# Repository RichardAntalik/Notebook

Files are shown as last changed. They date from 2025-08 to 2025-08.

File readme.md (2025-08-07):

# RPI CM5 based notebook

The design of small notebook with 8 inch display.
This is mainly a fun project, excersise in device production capability and integration
of complex systems at my home lab.

At revision 3 most subsystems are tested and working, but not as a whole.

## Features
- Smol
- 2 layer PCB layout! Optimized for home production
- Has integrated power management for 1S lipo pack
- Implements 4xUSB + 2 internal ports, 1x HDMI + 1 internal HDMI and DSI/CSI, PCIe, GPIO in card format and simple sound output

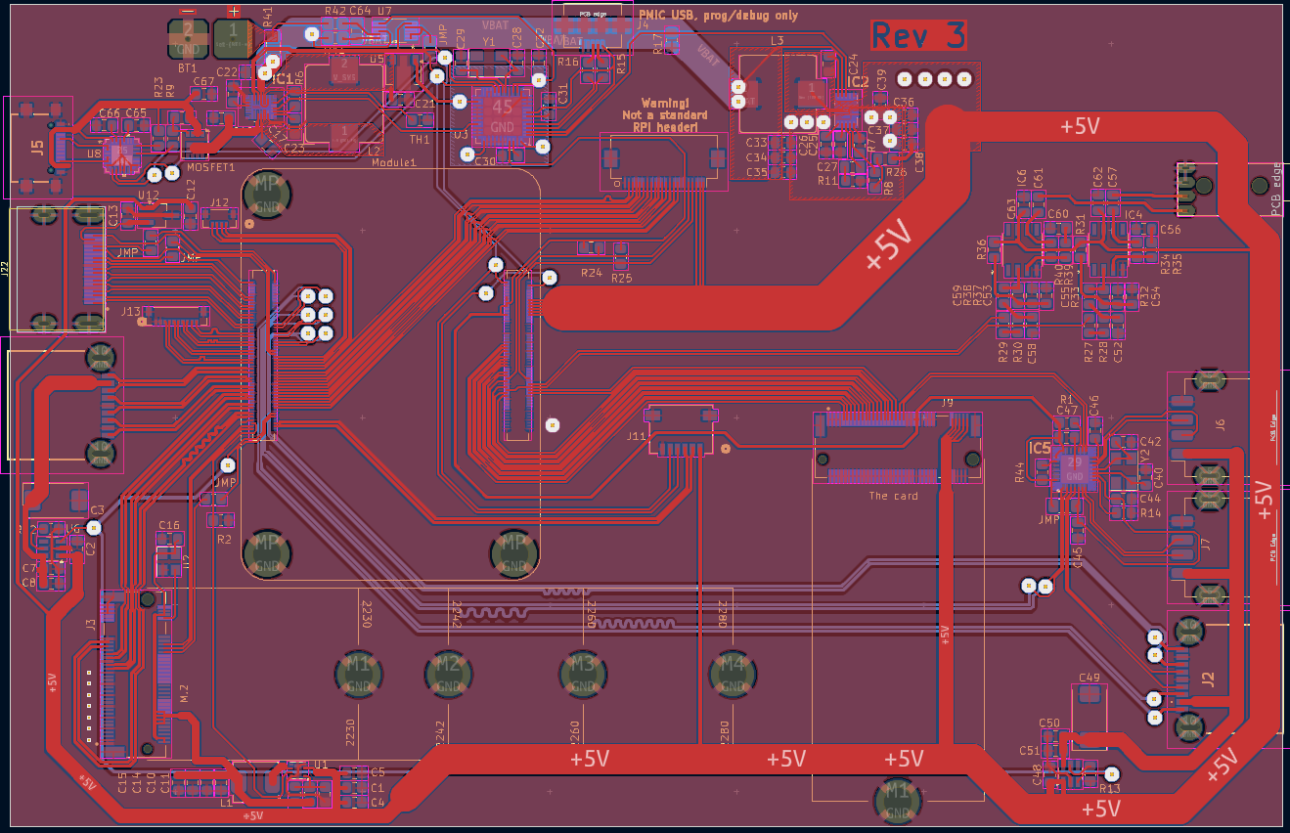
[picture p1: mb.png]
Main board


## TODO
- Custom keyboard with some touchpad or trackball or whatnot
- Display board
- Case

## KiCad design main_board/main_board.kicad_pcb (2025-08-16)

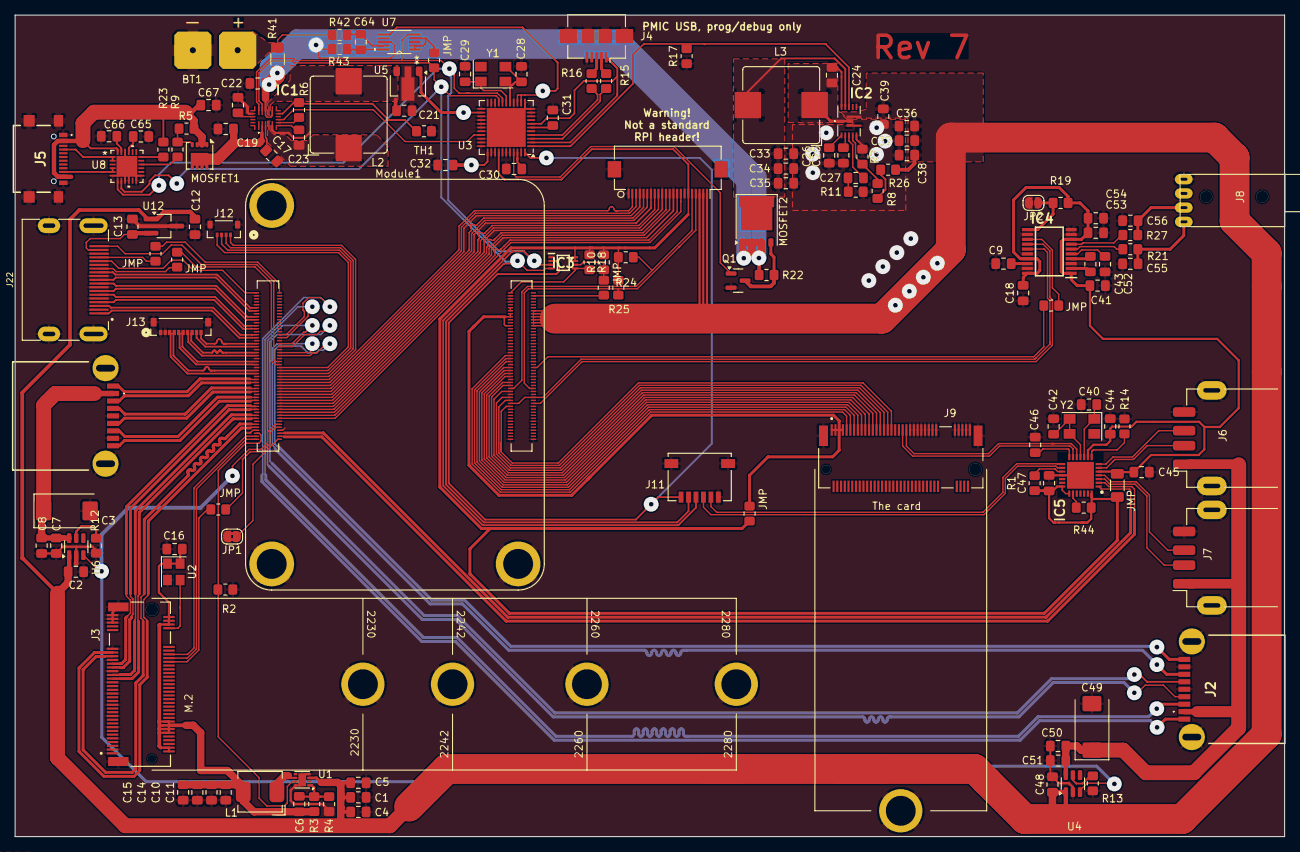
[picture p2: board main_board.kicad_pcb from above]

Board: 2 copper layers, 170.0 x 110.0 mm, 139 parts (0 on the bottom side), 161 nets.

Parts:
BT1: Battery_Cell; Bat_terminal
C1, C2, C4, C7, C8, C10, C11, C14, C15, C17, C20, C21, C22, C26, C48, C50, C51, C54: 10u; C_0805_2012Metric_Pad1.18x1.45mm_HandSolder
C3, C49: 100uF; CP_EIA-7343-31_Kemet-D
C5, C9, C12, C13, C16, C18, C24, C25, C39, C41, C44, C45, C46, C47, C53, C64: 100n; C_0805_2012Metric_Pad1.18x1.45mm_HandSolder
C6: 10nF; C_0805_2012Metric_Pad1.18x1.45mm_HandSolder
C19, C30, C31, C32, C65, C66, C67: 1u; C_0805_2012Metric_Pad1.18x1.45mm_HandSolder
C23, C27: 10n; C_0805_2012Metric_Pad1.18x1.45mm_HandSolder
C28, C29, C40, C42: 22p; C_0805_2012Metric_Pad1.18x1.45mm_HandSolder
C33, C34, C35, C36, C37, C38: 22u; C_0805_2012Metric_Pad1.18x1.45mm_HandSolder
C43, C52: 2u2; C_0805_2012Metric_Pad1.18x1.45mm_HandSolder
C55, C56: 2n2; C_0805_2012Metric_Pad1.18x1.45mm_HandSolder
IC1: MP2722GRH-0000-Z; MP2722GRH0000Z
IC2: MP3429GL-Z; MP3431GLP
IC3: PCA9306DCUR; SOP50P310X90-8N
IC4: PCM5102APWR; SOP65P640X120-20N
IC5: CY7C65632-28LTXC; QFN50P500X500X80-29N-D
J1, J2: USB3_A; U3BU1ASMT1
J3: Bus_M.2_Socket_M; M.2 M Key socket
J4: USB_B_Micro; USB_Micro-B_Amphenol_10104110_Horizontal
J5: USB_C_Receptacle_USB2.0; USB421603A
J6, J7: USB_A; USB_A_Receptacle_GCT_USB1046
J8: AudioJack3; LUMBERG 1503 16
J9: The_card; Random card conn
J10: Conn_01x22_Female; Hirose_FH12-22S-0.5SH_1x22-1MP_P0.50mm_Horizontal
J11: 501568-0607-TR325; CONN_501568-0607-TR325_MOL
J12: SM04B-XSRS-ETBLFSN; CONN_SM04B-XSRS-ETB_JST
J13: SM10B-XSRS-ETB; CONN_SM10B-XSRS-ETB_JST
J22: 690-019-298-412; EDAC 690-019-298-412
JMP: R_0805_2012Metric_Pad1.20x1.40mm_HandSolder
JMP#2, JMP#3, JMP#5, JMP#6, JMP#7, JMP#8: R_0805_2012Metric_Pad1.20x1.40mm_HandSolder
JMP#4: 0.01R; R_1206_3216Metric_Pad1.30x1.75mm_HandSolder
JP1: Jumper_2_Bridged; SolderJumper-2_P1.3mm_Bridged2Bar_RoundedPad1.0x1.5mm
JP2: Jumper_2; SolderJumper-2_P1.3mm_Open_RoundedPad1.0x1.5mm
L1: 2.2uH; L_Bourns_SRP5030CC
L2: 4.7u; L_Bourns_SRP1038C_10.0x10.0mm
L3: 1.5u; L_Bourns_SRP1038C_10.0x10.0mm
MOSFET1: STL9P3LLH6; Diodes_PowerDI3333-8
MOSFET2: WMB60P02TS-CYG; PQFN-8-EP_6x5mm_P1.27mm_Generic
Module1: ComputeModule5-CM5; Raspberry-Pi-5-Compute-Module
Q1: Random N ch FET; SOT-23
R1, R9: 10K; R_0805_2012Metric_Pad1.20x1.40mm_HandSolder
R2: 100K 1%; R_0805_2012Metric_Pad1.20x1.40mm_HandSolder
R3, R17: 15K; R_0805_2012Metric_Pad1.20x1.40mm_HandSolder
R4: 3.3K; R_0805_2012Metric_Pad1.20x1.40mm_HandSolder
R5, R7, R19, R22: 100K; R_0805_2012Metric_Pad1.20x1.40mm_HandSolder
R6: R=NTC; R_0805_2012Metric_Pad1.20x1.40mm_HandSolder
R8: 68K; R_0805_2012Metric_Pad1.20x1.40mm_HandSolder
R10, R18, R24, R25: 2K; R_0805_2012Metric_Pad1.20x1.40mm_HandSolder
R11: 6.8K; R_0805_2012Metric_Pad1.20x1.40mm_HandSolder
R12, R13: 15K 1%; R_0805_2012Metric_Pad1.20x1.40mm_HandSolder
R14: 650R; R_0805_2012Metric_Pad1.20x1.40mm_HandSolder
R15, R16: 20R; R_0805_2012Metric_Pad1.20x1.40mm_HandSolder
R21, R27: 470R; R_0805_2012Metric_Pad1.20x1.40mm_HandSolder
R23: 1K; R_0805_2012Metric_Pad1.20x1.40mm_HandSolder
R26: 330K; R_0805_2012Metric_Pad1.20x1.40mm_HandSolder
R41: 0.01R; R_1206_3216Metric_Pad1.30x1.75mm_HandSolder
R42, R43: 10R; R_0805_2012Metric_Pad1.20x1.40mm_HandSolder
R44: 100k; R_0805_2012Metric_Pad1.20x1.40mm_HandSolder
TH1: β = 3435; R_0805_2012Metric_Pad1.20x1.40mm_HandSolder
U1: AP3441SHE-7B; DFN-8-1EP_2x2mm_P0.5mm_EP1.05x1.75mm
U2: ASEK-32.768KHZ-L-R-T; Crystal_SMD_3225-4Pin_3.2x2.5mm
U3: ATmega32U4-M; QFN-44-1EP_7x7mm_P0.5mm_EP5.2x5.2mm
U4, U6: AP22653W6; SOT-23-6
U5: AP2204RB-3.3; SOT-89-3
U7: INA220AIDGST; DGS10
U8: STUSB4500QTR; STUSB4500
U12: RT9742SNGV; TSOT-23_HandSoldering
Y1: Crystal; Crystal_SMD_5032-4Pin_5.0x3.2mm
Y2: 12MHz; Crystal_SMD_5032-4Pin_5.0x3.2mm

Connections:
/Battery management/+5V: C1.1, C2.1, C4.1, C5.1, C12.1, C36.1, C37.1, C38.1, C39.1, C48.1, IC2.8 (VOUT), J10.20, J10.21, J10.22, Module1.77 (+5v_(Input)), Module1.79 (+5v_(Input)), Module1.81 (+5v_(Input)), Module1.83 (+5v_(Input)), Module1.85 (+5v_(Input)), Module1.87 (+5v_(Input)), R26.2, U1.3 (VIN), U4.1 (IN), U6.1 (IN), U12.1 (IN)
/Battery management/BOOST_EN: IC2.11 (EN), R17.2, U3.1 (PE6)
/Battery management/PMIC_3.3V: C32.2, IC3.2 (VREF1), J11.6, U3.13 (~RESET), U3.14 (VCC), U3.24 (AVCC), U3.34 (VCC), U3.44 (AVCC), U5.1 (VOUT), U7.6 (VS)
/Battery management/PMIC_IIC2_SCL: IC3.6 (SCL2), JMP#7.1, JMP#7.2, Module1.97 (CAM_GPIO0), R10.1
/Battery management/PMIC_IIC2_SDA: IC3.5 (SDA2), Module1.100 (CAM_GPIO1), R18.2
/Battery management/PMIC_IIC_SCL: IC1.16 (SCL), IC3.3 (SCL1), J11.4, U3.18 (PD0), U7.5 (SCL), U8.7 (SCL)
/Battery management/PMIC_IIC_SDA: IC1.15 (SDA), IC3.4 (SDA1), J11.5, JMP#3.1, U3.19 (PD1), U7.1 (A1), U7.2 (A0), U7.4 (SDA), U8.8 (SDA)
/Battery management/VBAT: C22.1, IC1.12 (BATTSNS), IC1.14 (BATT), MOSFET2.1 (S), MOSFET2.2 (S), MOSFET2.3 (S), R22.2, R41.2, R43.2, U7.8 (VBUS)
/Battery management/V_SYS: C21.1, IC1.13 (SYS), L2.2, U5.3 (VIN)
/CM5_GPIO/+1.8v: Module1.88 (+1.8v_(Output)), Module1.90 (+1.8v_(Output))
/CM5_GPIO/+3.3v: C18.1, C41.2, C44.1, C45.1, C47.1, C53.2, C54.2, IC3.7 (VREF2), IC3.8 (EN), IC4.1 (CPVDD), IC4.8 (AVDD), IC4.17 (XSMT), IC4.20 (DVDD), IC5.5 (VCC_A_1), IC5.9 (VCC_A_2), IC5.21 (VCC_D), IC5.22 (SELFPWR), IC5.28 (VREG), J9.1, J9.3, J9.5, J9.7, J10.17, JMP#4.1, JMP#4.2, JMP#5.1, JMP#5.2, Module1.78 (GPIO_VREF(1.8v/3.3v_Input)), Module1.84 (+3.3v_(Output)), Module1.86 (+3.3v_(Output)), R1.1, R10.2, R18.1, R19.2, R24.1, R25.1, R44.1, U3.37 (PF6)
/CM5_GPIO/DPHY1_SCL: J10.19, Module1.35 (ID_SC), R25.2
/CM5_GPIO/DPHY1_SDA: J10.18, Module1.36 (ID_SD), R24.2
/CM5_GPIO/GP2: J9.9, Module1.58 (GPIO2)
/CM5_GPIO/GP3: J9.11, Module1.56 (GPIO3)
/CM5_GPIO/GP4: J9.13, Module1.54 (GPIO4)
/CM5_GPIO/GP5: J9.27, Module1.34 (GPIO5)
/CM5_GPIO/GP6: J9.29, Module1.30 (GPIO6)
/CM5_GPIO/GP9: J9.23, Module1.40 (GPIO9)
/CM5_GPIO/GP10: J9.21, Module1.44 (GPIO10)
/CM5_GPIO/GP11: J9.25, Module1.38 (GPIO11)
/CM5_GPIO/GP13: J9.31, Module1.28 (GPIO13)
/CM5_GPIO/GP17: J9.15, Module1.50 (GPIO17)
/CM5_GPIO/GP22: J9.19, Module1.46 (GPIO22)
/CM5_GPIO/GP26: J9.33, Module1.24 (GPIO26)
/CM5_GPIO/GP27: J9.17, Module1.48 (GPIO27)
/CM5_GPIO/GPIO16: IC4.15 (LRCK), Module1.26 (GPIO19), Module1.29 (GPIO16)
/CM5_GPIO/I2SCLK: IC4.13 (BCK), JMP#6.1, JMP#6.2, Module1.49 (GPIO18)
/CM5_HighSpeed/DPHY0_C_N: J10.9, Module1.127 (MIPI0_C_N)
/CM5_HighSpeed/DPHY0_C_P: J10.8, Module1.129 (MIPI0_C_P)
/CM5_HighSpeed/DPHY0_D0_N: J10.15, Module1.115 (MIPI0_D0_N)
/CM5_HighSpeed/DPHY0_D0_P: J10.14, Module1.117 (MIPI0_D0_P)
/CM5_HighSpeed/DPHY0_D1_N: J10.12, Module1.121 (MIPI0_D1_N)
/CM5_HighSpeed/DPHY0_D1_P: J10.11, Module1.123 (MIPI0_D1_P)
/CM5_HighSpeed/DPHY0_D2_N: J10.6, Module1.133 (MIPI0_D2_N)
/CM5_HighSpeed/DPHY0_D2_P: J10.5, Module1.135 (MIPI0_D2_P)
/CM5_HighSpeed/DPHY0_D3_N: J10.3, Module1.139 (MIPI0_D3_N)
/CM5_HighSpeed/DPHY0_D3_P: J10.2, Module1.141 (MIPI0_D3_P)
/CM5_HighSpeed/HDMI0_CEC: J22.13 (CEC), JMP#2.1, JMP#2.2, Module1.151 (HDMI0_CEC)
/CM5_HighSpeed/HDMI0_CK_N: J22.12 (CK-), Module1.190 (HDMI0_CLK_N)
/CM5_HighSpeed/HDMI0_CK_P: J22.10 (CK+), Module1.188 (HDMI0_CLK_P)
/CM5_HighSpeed/HDMI0_D0_N: J22.9 (D0-), Module1.184 (HDMI0_TX0_N)
/CM5_HighSpeed/HDMI0_D0_P: J22.7 (D0+), Module1.182 (HDMI0_TX0_P)
/CM5_HighSpeed/HDMI0_D1_N: J22.6 (D1-), Module1.178 (HDMI0_TX1_N)
/CM5_HighSpeed/HDMI0_D1_P: J22.4 (D1+), Module1.176 (HDMI0_TX1_P)
/CM5_HighSpeed/HDMI0_D2_N: J22.3 (D2-), Module1.172 (HDMI0_TX2_N)
/CM5_HighSpeed/HDMI0_D2_P: J22.1 (D2+), Module1.170 (HDMI0_TX2_P)
/CM5_HighSpeed/HDMI0_HOTPLUG: J22.19 (HPD/HEAC-), Module1.153 (HDMI0_HOTPLUG)
/CM5_HighSpeed/HDMI0_SCL: J22.15 (SCL), Module1.200 (HDMI0_SCL)
/CM5_HighSpeed/HDMI0_SDA: J22.16 (SDA), JMP#8.1, JMP#8.2, Module1.199 (HDMI0_SDA)
/CM5_HighSpeed/HDMI1_CEC: J12.4, Module1.149 (HDMI1_CEC)
/CM5_HighSpeed/HDMI1_CK_N: J13.10, Module1.166 (HDMI1_CLK_N)
/CM5_HighSpeed/HDMI1_CK_P: J13.9, Module1.164 (HDMI1_CLK_P)
/CM5_HighSpeed/HDMI1_D0_N: J13.8, Module1.160 (HDMI1_TX0_N)
/CM5_HighSpeed/HDMI1_D0_P: J13.7, Module1.158 (HDMI1_TX0_P)
/CM5_HighSpeed/HDMI1_D1_N: J13.6, Module1.154 (HDMI1_TX1_N)
/CM5_HighSpeed/HDMI1_D1_P: J13.5, Module1.152 (HDMI1_TX1_P)
/CM5_HighSpeed/HDMI1_D2_N: J13.4, Module1.148 (HDMI1_TX2_N)
/CM5_HighSpeed/HDMI1_D2_P: J13.3, Module1.146 (HDMI1_TX2_P)
/CM5_HighSpeed/HDMI1_HOTPLUG: J12.1, Module1.143 (HDMI1_HOTPLUG)
/CM5_HighSpeed/HDMI1_SCL: J12.3, Module1.147 (HDMI1_SCL)
/CM5_HighSpeed/HDMI1_SDA: J12.2, Module1.145 (HDMI1_SDA)
/CM5_HighSpeed/HDMI_5v: C13.1, J22.18 (+5V), U12.2 (OUT)
/CM5_HighSpeed/PCIE_CLK_N: J3.53 (REFCLKn), Module1.112 (PCIe_CLK_N)
/CM5_HighSpeed/PCIE_CLK_P: J3.55 (REFCLKp), Module1.110 (PCIe_CLK_P)
/CM5_HighSpeed/PCIE_PWR_EN: Module1.106 (PCIE_PWR_EN), R2.1, U1.7 (EN)
/CM5_HighSpeed/PCIE_RX_N: J3.43 (PETp0), Module1.118 (PCIe_RX_N)
/CM5_HighSpeed/PCIE_RX_P: J3.41 (PETn0), Module1.116 (PCIe_RX_P)
/CM5_HighSpeed/PCIE_TX_N: J3.49 (PERp0), Module1.124 (PCIe_TX_N)
/CM5_HighSpeed/PCIE_TX_P: J3.47 (PERn0), Module1.122 (PCIe_TX_P)
/CM5_HighSpeed/PCIE_nCLKREQ: J3.52 (~CLKREQ), Module1.102 (PCIe_nCLKREQ)
/CM5_HighSpeed/PCIE_nRST: J3.50 (~PERST), JMP.1, JMP.2, Module1.109 (PCIe_nRST)
/CM5_HighSpeed/PCIE_nWAKE: J3.54 (~PEWAKE), Module1.104 (PCIE_nWAKE)
/CM5_HighSpeed/USB2_N: IC5.1 (D-), Module1.105 (USB2_P)
/CM5_HighSpeed/USB2_P: IC5.2 (D+), Module1.103 (USB2_N)
/CM5_HighSpeed/USB3-0-D_N: J1.2 (D-), Module1.136 (USB3-0-D_N)
/CM5_HighSpeed/USB3-0-D_P: J1.3 (D+), Module1.134 (USB3-0-D_P)
/CM5_HighSpeed/USB3-0-RX_N: J1.5 (SSRX-), Module1.128 (USB3-0-RX_N)
/CM5_HighSpeed/USB3-0-RX_P: J1.6 (SSRX+), Module1.130 (USB3-0-RX_P)
/CM5_HighSpeed/USB3-0-TX_N: J1.8 (SSTX-), Module1.140 (USB3-0-TX_N)
/CM5_HighSpeed/USB3-0-TX_P: J1.9 (SSTX+), Module1.142 (USB3-0-TX_P)
/CM5_HighSpeed/VBUS: C3.1, C7.1, C8.1, J1.1 (VBUS), U6.6 (OUT)
/CM5_HighSpeed/VBUS_EN: Module1.111 (VBUS_EN), U4.3 (EN), U6.3 (EN)
/PCIe-M2/FB: C6.2, R3.2, R4.1, U1.1 (FB)
/PCIe-M2/M2_3v3: C6.1, C10.1, C11.1, C14.1, C15.1, C16.1, J3.2 (3.3V), J3.4 (3.3V), J3.12 (3.3V), J3.14 (3.3V), J3.16 (3.3V), J3.18 (3.3V), J3.70 (3.3V), J3.72 (3.3V), J3.74 (3.3V), L1.2, R3.1, U2.1 (EN), U2.4 (VDD)
/The card/USB2_2_DN: IC5.12 (DD-[3]), J9.41
/The card/USB2_2_DP: IC5.13 (DD+[3]), J9.39
/USB hub/VBUS2: C49.1, C50.1, C51.1, J2.1 (VBUS), J6.1 (VBUS), J7.1 (VBUS), U4.6 (OUT)
GND: BT1.2 (-), C1.2, C2.2, C3.2, C4.2, C5.2, C7.2, C8.2, C9.2, C10.2, C11.2, C12.2, C13.2, C14.2, C15.2, C16.2, C17.2, C18.2, C19.2, C20.2, C21.2, C22.2, C25.1, C26.1, C28.2, C29.2, C30.1, C31.1, C32.1, C33.2, C34.2, C35.2, C36.2, C37.2, C38.2, C39.2, C40.2, C41.1, C42.2, C44.2, C45.2, C46.2, C47.2, C48.2, C49.2, C50.2, C51.2, C52.1, C53.1, C54.1, C55.1, C56.1, C65.2, C66.2, C67.2, IC1.5 (PGND), IC1.18 (AGND), IC2.6 (AGND), IC2.7 (PGND), IC2.9 (FTY), IC3.1 (GND), IC4.3 (CPGND), IC4.9 (AGND), IC4.10 (DEMP), IC4.12 (SCK), IC4.16 (FMT), IC4.19 (DGND), IC5.18 (TEST/_I2C_SCL), IC5.29 (EP), J1.4 (GND), J1.7 (DRAIN), J1.10 (SHIELD), J2.4 (GND), J2.7 (DRAIN), J2.10 (SHIELD), J3.1 (GND), J3.3 (GND), J3.9 (GND), J3.15 (GND), J3.21 (GND), J3.27 (GND), J3.33 (GND), J3.39 (GND), J3.45 (GND), J3.51 (GND), J3.57 (GND), J3.71 (GND), J3.73 (GND), J3.75 (GND), J3.M1 (GND2230), J3.M2 (GND2242), J3.M3 (GND2260), J3.M4 (GND2280), J3.S1, J3.S2, J4.5 (GND), J4.6 (Shield), J5.A1 (GND), J5.B1 (GND), J5.S1 (SHIELD), J6.4 (GND), J6.5 (Shield), J7.4 (GND), J7.5 (Shield), J8.S, J9.43, J9.45, J9.47, J9.49, J9.51, J9.53, J9.55, J9.57, J9.67, J9.69, J9.71, J9.73, J9.75, J9.M1 (GND2230), J9.S1, J9.S2, J10.1, J10.4, J10.7, J10.10, J10.13, J10.16, J10.MP, J11.1, J11.7, J11.8, J12.5, J12.6, J13.1, J13.2, J13.11, J13.12, J22.2 (D2S), J22.5 (D1S), J22.8 (D0S), J22.11 (CKS), J22.17 (GND), J22.SH1 (SH), J22.SH2 (SH), J22.SH3 (SH), J22.SH4 (SH), JP1.2 (B), JP2.2 (B), Module1.1 (GND), Module1.2 (GND), Module1.7 (GND), Module1.8 (GND), Module1.13 (GND), Module1.14 (GND), Module1.22 (GND), Module1.23 (GND), Module1.32 (GND), Module1.33 (GND), Module1.42 (GND), Module1.43 (GND), Module1.52 (GND), Module1.53 (GND), Module1.59 (GND), Module1.60 (GND), Module1.65 (GND), Module1.66 (GND), Module1.71 (GND), Module1.74 (GND), Module1.94 (CC1), Module1.96 (CC2), Module1.98 (GND), Module1.107 (GND), Module1.108 (GND), Module1.113 (GND), Module1.114 (GND), Module1.119 (GND), Module1.120 (GND), Module1.125 (GND), Module1.126 (GND), Module1.131 (GND), Module1.132 (GND), Module1.137 (GND), Module1.138 (GND), Module1.144 (GND), Module1.150 (GND), Module1.155 (GND), Module1.156 (GND), Module1.161 (GND), Module1.162 (GND), Module1.167 (GND), Module1.168 (GND), Module1.173 (GND), Module1.174 (GND), Module1.179 (GND), Module1.180 (GND), Module1.185 (GND), Module1.186 (GND), Module1.191 (GND), Module1.192 (GND), Module1.197 (GND), Module1.198 (GND), Module1.MP, Q1.2 (S), R2.2, R4.2, R7.1, R11.1, R12.1, R13.2, R14.2, R17.1, TH1.2, U1.4 (PGND), U1.8 (SGND), U1.9 (PAD), U2.2 (GND), U3.5 (UGND), U3.9 (PB1), U3.10 (PB2), U3.11 (PB3), U3.12 (PB7), U3.15 (GND), U3.20 (PD2), U3.21 (PD3), U3.23 (GND), U3.25 (PD4), U3.26 (PD6), U3.27 (PD7), U3.28 (PB4), U3.29 (PB5), U3.31 (PC6), U3.32 (PC7), U3.33 (~HWB/PE2), U3.35 (GND), U3.36 (PF7), U3.38 (PF5), U3.39 (PF4), U3.40 (PF1), U3.43 (GND), U3.45 (GND), U4.2 (GND), U5.2 (GND), U6.2 (GND), U7.7 (GND), U8.6 (RESET), U8.9 (DISCH), U8.10 (GND), U8.12 (ADDR0), U8.13 (ADDR1), U8.22 (VSYS), U8.25 (EP), U12.3 (GND)
unnamed: BT1.1 (+), R41.1, R42.2
unnamed: C27.1, R11.2
unnamed: C55.2, J8.T, R21.1
unnamed: C56.2, J8.R1, R27.1
unnamed: C23.2, IC1.6 (BST_1)
unnamed: C19.1, IC1.2 (IN), MOSFET1.5 (D)
unnamed: IC1.10 (NTC1), R6.1, TH1.1
unnamed: C17.1, IC1.3 (PMID)
unnamed: C23.1, IC1.4 (SW), L2.1
unnamed: C20.1, IC1.19 (VCC)
unnamed: IC1.7 (VRNTC), R6.2
unnamed: IC1.8 (~INT), U3.30 (PB6)
unnamed: C24.1, IC2.13 (BST)
unnamed: C27.2, IC2.4 (COMP)
unnamed: IC2.5 (FB), R7.2, R8.1
unnamed: C25.2, IC2.3 (SS)
unnamed: C24.2, IC2.1 (SW), L3.1
unnamed: C26.2, IC2.2 (VDD)
unnamed: C33.1, C34.1, C35.1, IC2.12 (VIN), L3.2, MOSFET2.5 (D)
unnamed: C43.1, IC4.4 (CAPM)
unnamed: C43.2, IC4.2 (CAPP)
unnamed: IC4.14 (DIN), Module1.25 (GPIO21)
unnamed: IC4.11 (FLT), JP2.1 (A), R19.1
unnamed: C9.1, IC4.18 (LDOO)
unnamed: IC4.6 (OUTL), R21.2
unnamed: IC4.7 (OUTR), R27.2
unnamed: C52.2, IC4.5 (VNEG)
unnamed: IC5.4 (DD+[1]), J7.3 (D+)
unnamed: IC5.7 (DD+[2]), J6.3 (D+)
unnamed: IC5.16 (DD+[4]), J11.3
unnamed: IC5.3 (DD-[1]), J7.2 (D-)
unnamed: IC5.6 (DD-[2]), J6.2 (D-)
unnamed: IC5.15 (DD-[4]), J11.2
unnamed: IC5.23 (GANG), R44.2
unnamed: IC5.17 (RESET#), R1.2
unnamed: IC5.8 (RREF), R14.1
unnamed: C46.1, IC5.14 (VCC_A_3)
unnamed: C40.1, IC5.10 (XIN), Y2.1
unnamed: C42.1, IC5.11 (XOUT), Y2.2
unnamed: J2.3 (D+), Module1.163 (USB3-1-D_P)
unnamed: J2.2 (D-), Module1.165 (USB3-1-D_N)
unnamed: J2.6 (SSRX+), Module1.157 (USB3-1-RX_N)
unnamed: J2.5 (SSRX-), Module1.159 (USB3-1-RX_P)
unnamed: J2.9 (SSTX+), Module1.171 (USB3-1-TX_P)
unnamed: J2.8 (SSTX-), Module1.169 (USB3-1-TX_N)
unnamed: J3.68 (SUSCLK), U2.3 (Out)
unnamed: J4.3 (D+), R16.2
unnamed: J4.2 (D-), R15.2
unnamed: J4.1 (VBUS), U3.2 (UVCC), U3.7 (VBUS)
unnamed: J5.A5 (CC1), U8.1 (CC1DB), U8.2 (CC1)
unnamed: J5.B5 (CC2), U8.4 (CC2), U8.5 (CC2DB)
unnamed: JP1.1 (A), Module1.101 (USB_OTG_ID)
unnamed: MOSFET1.4 (G), R5.2, R9.1
unnamed: MOSFET2.4 (G), Q1.3 (D), R22.1
unnamed: Q1.1 (G), U3.41 (PF0)
unnamed: R8.2, R26.1
unnamed: L1.1, U1.6 (LX)
unnamed: C30.2, U3.42 (AREF)
unnamed: R16.1, U3.4 (D+)
unnamed: R15.1, U3.3 (D-)
unnamed: C31.2, U3.6 (UCAP)
unnamed: C29.1, U3.17 (XTAL1), Y1.1
unnamed: C28.1, U3.16 (XTAL2), Y1.2
unnamed: R13.1, U4.5 (ILIM)
unnamed: R12.2, U6.5 (ILIM)
unnamed: C64.2, R43.1, U7.10 (VIN+)
unnamed: C64.1, R42.1, U7.9 (VIN-)
unnamed: R9.2, U8.16 (VBUS_EN_SNK)
unnamed: R23.2, U8.18 (VBUS_VS_DISCH)
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

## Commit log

2025-06-30 Add main board project
    [CM5_GPIO.kicad_sch, CM5_HighSpeed.kicad_sch, PCIe-M2.kicad_sch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]
2025-06-30 Implement part of power management.
    [CM5_GPIO.kicad_sch, PCIe-M2.kicad_sch, bat.kicad_sch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]
2025-07-01 More power management goodness
    [CM5_GPIO.kicad_sch, CM5_HighSpeed.kicad_sch, PCIe-M2.kicad_sch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]
2025-07-02 Finalize power management
    [CM5_GPIO.kicad_sch, CM5_HighSpeed.kicad_sch, bat.kicad_sch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]
2025-07-03 Start reouting USB hub
    [CM5_HighSpeed.kicad_sch, bat.kicad_sch, main_board.kicad_pcb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]
2025-07-06 Bunch more routing, mainly added MIPI interface, reworked power management a bit
    [CM5_GPIO.kicad_sch, CM5_HighSpeed.kicad_sch, bat.kicad_sch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]
2025-07-12 Bunch of fixes + audio out interface
    [CM5_GPIO.kicad_sch, bat.kicad_sch, main_board.kicad_pcb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]
2025-07-12 Implement power monitoring
    [CM5_GPIO.kicad_sch, CM5_HighSpeed.kicad_sch, bat.kicad_sch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]
2025-07-13 Add expansion slot
    [CM5_GPIO.kicad_sch, bat.kicad_sch, main_board.kicad_pcb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]
2025-07-27 Rev 1 draft
    [CM5_HighSpeed.kicad_sch, PCIe-M2.kicad_sch, bat.kicad_sch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]
2025-07-27 Cleanup silks
    [main_board.kicad_pcb]
2025-07-28 Final fixes
    [bat.kicad_sch, main_board.kicad_pcb]
2025-07-28 Also update schematic
    [bat.kicad_sch]
2025-07-29 Fix fried USB hub
    [bat.kicad_sch, main_board.kicad_pcb]
2025-07-30 Fix frying usb hub again
    [main_board.kicad_pcb]
2025-07-30 Remove passives from hub
    [main_board.kicad_pcb, main_board.kicad_sch]
2025-07-30 Cleanup, improve ground situation
    [main_board.kicad_pcb]
2025-07-30 More ground improvements
    [main_board.kicad_pcb]
2025-08-04 Fix 32u4 high power consumption, improve QFN soldering with thick ass solder masks.
    [bat.kicad_sch, main_board.kicad_pcb]
2025-08-05 Make sure, that audio jack can be hand soldered, finalize rev 1 design.
    [CM5_GPIO.kicad_sch, main_board.kicad_pcb, main_board.kicad_sch]
2025-08-05 Fix bad jack footprint
    [main_board.kicad_pcb]
2025-08-05 Make all holes only 0.8mm for spot drilling only
    [main_board.kicad_pcb]
2025-08-05 Add battery polarity labels to cu layer, since mistake would be expensive
    [main_board.kicad_pcb]
2025-08-05 Change the board size, rev2
    [main_board.kicad_pcb]
2025-08-07 Revert all holes defaulting to 0.8mm as plotter can do this
    [main_board.kicad_pcb]
2025-08-07 Add mounting points to symbols
    [CM5_GPIO.kicad_sch, CM5_HighSpeed.kicad_sch, main_board.kicad_pcb]
2025-08-07 Make more space for the card
    [main_board.kicad_pcb]
2025-08-07 Change mech holes to TH for better hand spot drilling
    [main_board.kicad_pcb]
2025-08-07 Silk cleanup
    [main_board.kicad_pcb]
2025-08-07 Update readme and whatnot
    [main_board.kicad_pcb]
2025-08-10 Rev 4
    Fix some mistakes found during assembly
    [main_board.kicad_pcb]
2025-08-10 Fix bad output voltage
    For some reason I got 5V with previous values on prototype. Weird...
    [CM5_GPIO.kicad_sch, CM5_HighSpeed.kicad_sch, PCIe-M2.kicad_sch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]
2025-08-12 Fix critical problems
    - Adding USB2 hub on USB3 port did not work correctly
    - PM I2C bus was not working when CM5 is shut down
    - Missing OTG ID pin
    [CM5_GPIO.kicad_sch, CM5_HighSpeed.kicad_sch, bat.kicad_sch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]
2025-08-13 Fix CM5 not waking up when enabling boost
    When battery is fully charged, CM5 does not turn on.
    [CM5_GPIO.kicad_sch, CM5_HighSpeed.kicad_sch, bat.kicad_sch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]
2025-08-15 Use I2S sound chip instead of PWM output
    [CM5_GPIO.kicad_sch, main_board.kicad_pcb, main_board.kicad_sch]
2025-08-16 Minor fixes
    [CM5_GPIO.kicad_sch, main_board.kicad_pcb]

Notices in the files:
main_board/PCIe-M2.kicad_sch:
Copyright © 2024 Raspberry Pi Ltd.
